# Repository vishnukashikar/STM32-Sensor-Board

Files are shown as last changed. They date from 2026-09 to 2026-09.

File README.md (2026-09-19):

# STM32 Sensor Board

A small custom board built around an **STM32C031C6** microcontroller and an **MPU-6050** 6-axis accelerometer/gyroscope (I2C), designed in KiCad.

**Status:** v1 (2026-09-17), design complete, not yet fabricated or tested.

This is a hardware design project: the repository contains the KiCad schematic and PCB layout only, with no firmware.

| Front | Back |
|---|---|
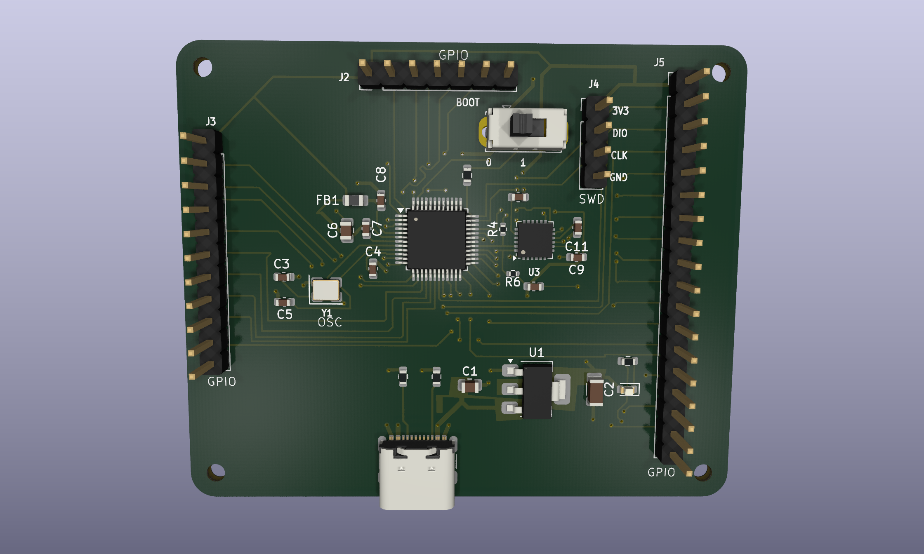
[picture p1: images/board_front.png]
Front
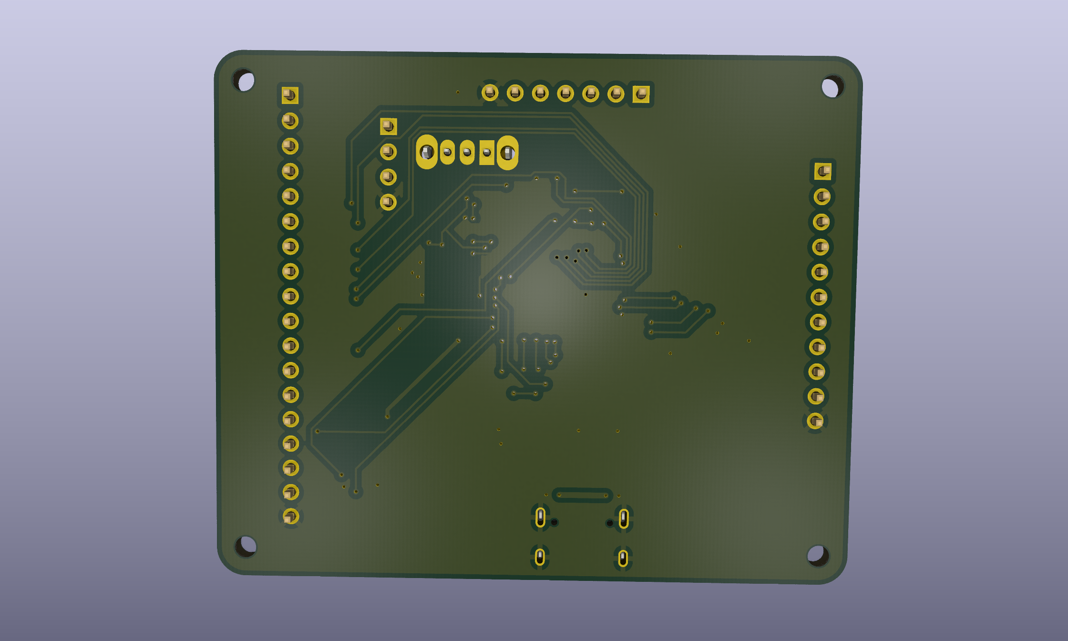
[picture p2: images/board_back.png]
Back
|  |  |

## Hardware overview

| Ref | Part | Role |
|---|---|---|
| U2 | STM32C031C6Tx (LQFP-48) | Main MCU |
| U3 | MPU-6050 (QFN-24, 4x4 mm) | Accelerometer + gyroscope |
| U1 | AMS1117-3.3 (SOT-223) | 5 V to 3.3 V regulator |
| J1 | USB-C receptacle | 5 V power input (VBUS) |
| Y1 | 16 MHz crystal (3225) with 16 pF load caps (C3, C5) | MCU clock |
| SW1 | SPDT slide switch | BOOT0 select (silkscreen: BOOT 0/1) |
| J4 | 1x4 header | SWD: 3V3, DIO, CLK, GND |
| J2, J3, J5 | 1x7, 1x11, 1x18 headers | GPIO breakout |
| D1 + R3 | LED + 300 ohm | Status LED |
| R4, R6 | 4.7 k | I2C pull-ups |
| FB1 + C6 | 120 ohm ferrite bead + 4.5 uF | Analog supply filtering (+3.3VA) |

Board: 2-layer, about 65.5 x 54 mm, four M2 mounting holes.

## Key connections

| Signal | U2 (MCU) pin | Goes to |
|---|---|---|
| I2C1_SCL | 29 | MPU-6050 SCL (U3 pin 23) |
| I2C1_SDA | 32 | MPU-6050 SDA (U3 pin 24) |
| MPU_INT | 33 | MPU-6050 INT (U3 pin 12) |
| SWCLK / SWDIO | 36 / 35 | J4 |
| NRST | 10 | Reset net |

The remaining MCU pins are broken out to J2, J3 and J5. See the schematic for the full pin mapping.

## Repository layout

```
hardware/   KiCad project (schematic, PCB, project file)
images/     3D renders of the board
```

## Programming and debug interface

The board exposes SWD on header J4 (3V3, DIO, CLK, GND). The USB-C port is used for power only; its data lines are not routed to the MCU.

## Opening the design

Open `hardware/stm32_sensor_board.kicad_pro` in KiCad.

## License

MIT, see [LICENSE](LICENSE).

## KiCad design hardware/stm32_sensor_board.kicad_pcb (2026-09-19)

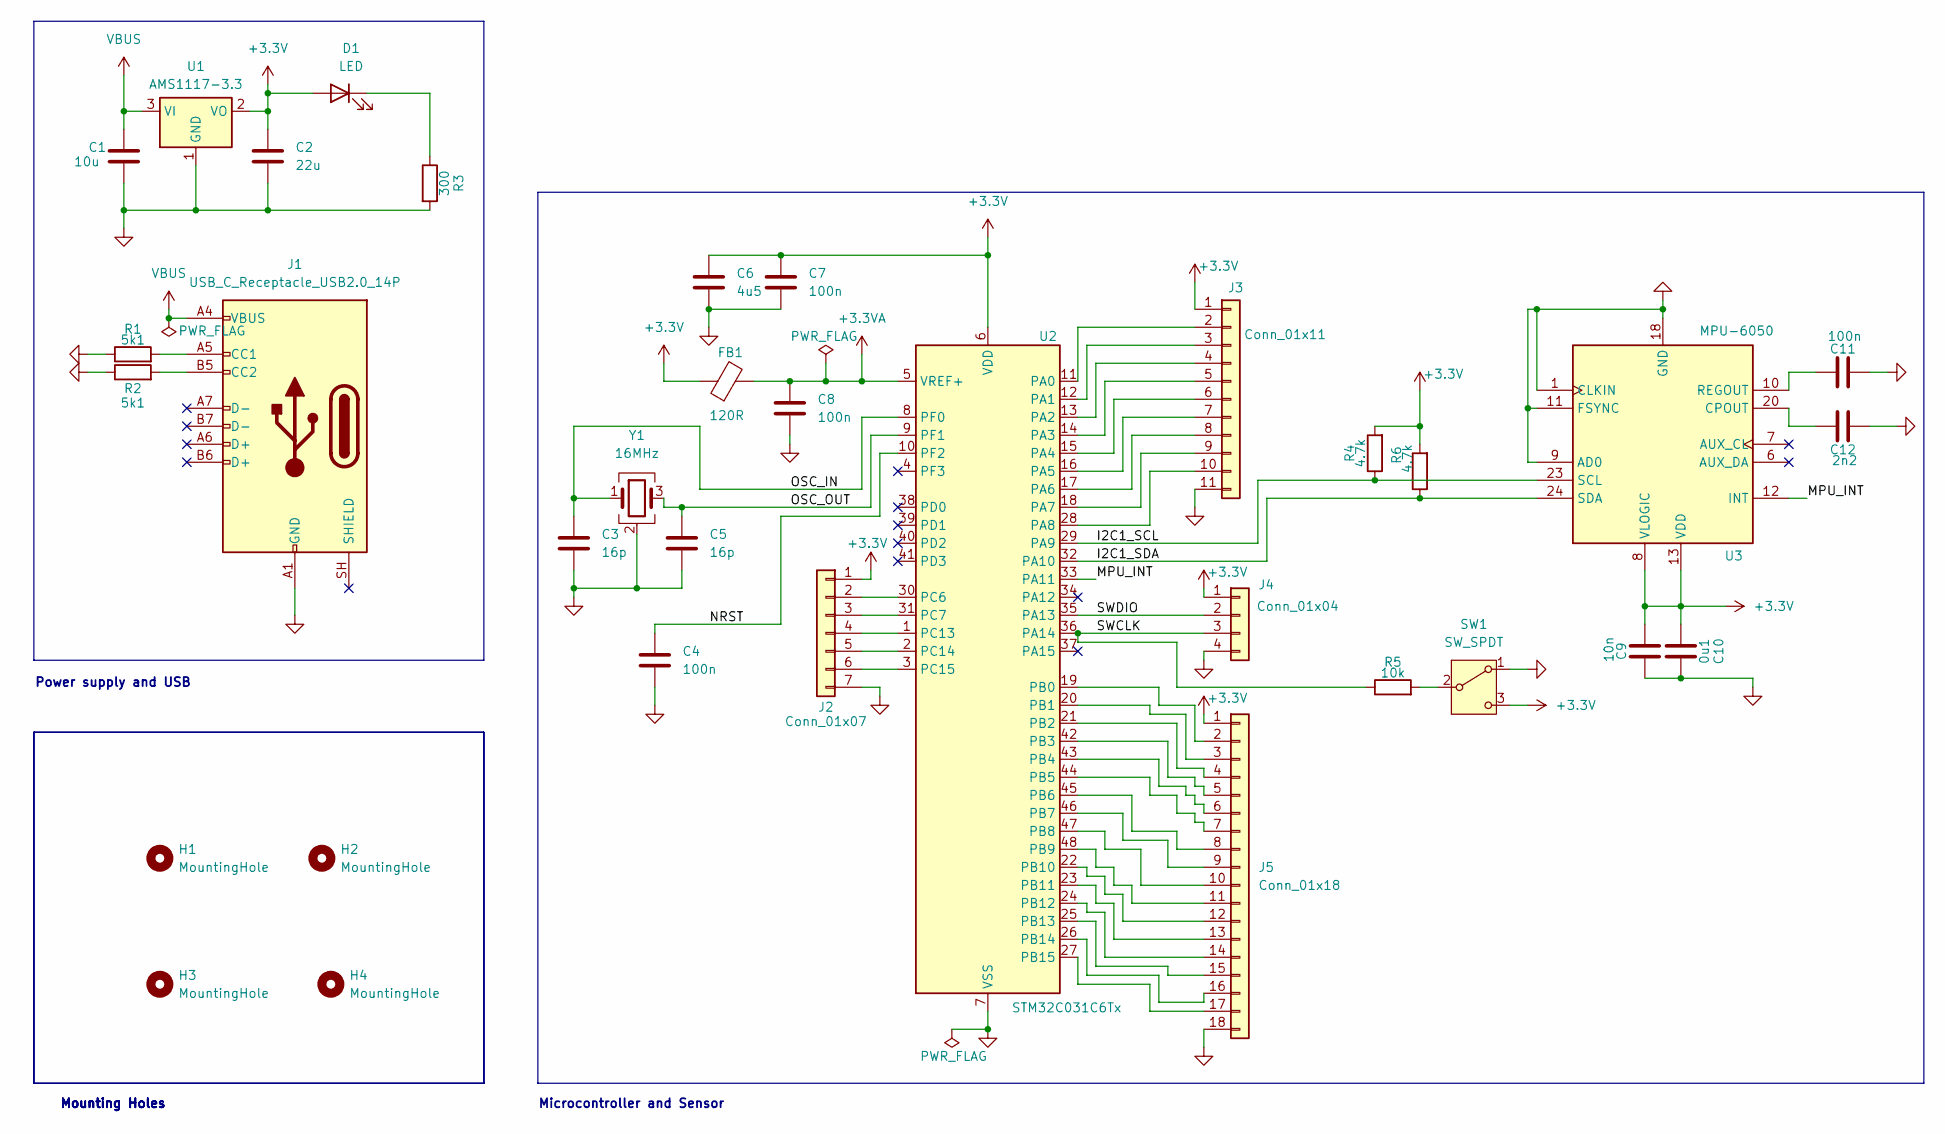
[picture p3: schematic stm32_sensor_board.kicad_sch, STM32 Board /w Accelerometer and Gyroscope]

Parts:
C1: 10u; C_0805_2012Metric
C2: 22u; C_1206_3216Metric
C3, C5: 16p; C_0603_1608Metric
C4, C7, C8, C11: 100n; C_0603_1608Metric
C6: 4u5; C_0805_2012Metric
C9: 10n; C_0603_1608Metric
C10: 0u1; C_0603_1608Metric
C12: 2n2; C_0603_1608Metric
D1: LED; LED_0603_1608Metric
FB1: 120R; L_0805_2012Metric
H1, H2, H3, H4: MountingHole; MountingHole_2.2mm_M2
J1: USB_C_Receptacle_USB2.0_14P; USB_C_Receptacle_GCT_USB4105-xx-A_16P_TopMnt_Horizontal
J2: Conn_01x07; PinHeader_1x07_P2.54mm_Vertical
J3: Conn_01x11; PinHeader_1x11_P2.54mm_Vertical
J4: Conn_01x04; PinHeader_1x04_P2.54mm_Vertical
J5: Conn_01x18; PinHeader_1x18_P2.54mm_Vertical
R1, R2: 5k1; R_0603_1608Metric
R3: 300; R_0603_1608Metric
R4, R6: 4.7k; R_0402_1005Metric
R5: 10k; R_0603_1608Metric
SW1: SW_SPDT; SW_Slide_SPDT_Straight_CK_OS102011MS2Q
U1: AMS1117-3.3; SOT-223-3_TabPin2
U2: STM32C031C6Tx; LQFP-48_7x7mm_P0.5mm
U3: MPU-6050; InvenSense_QFN-24_4x4mm_P0.5mm
Y1: 16MHz; Crystal_SMD_3225-4Pin_3.2x2.5mm

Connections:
+3.3V: C2.1, C6.1, C7.1, C9.2, C10.2, D1.2 (A), FB1.1, J2.1, J3.1, J4.1, J5.1, R4.2, R6.2, SW1.3 (C), U1.2 (VO), U2.6 (VDD), U3.8 (VLOGIC), U3.13 (VDD)
+3.3VA: C8.1, FB1.2, U2.5 (VREF+)
/I2C1_SCL: R4.1, U2.29 (PA9), U3.23 (SCL)
/I2C1_SDA: R6.1, U2.32 (PA10), U3.24 (SDA)
/MPU_INT: U2.33 (PA11), U3.12 (INT)
/NRST: C4.1, U2.10 (PF2)
/OSC_IN: C3.1, U2.8 (PF0), Y1.1
/OSC_OUT: C5.1, U2.9 (PF1), Y1.3
/SWCLK: J4.3, R5.1, U2.36 (PA14)
/SWDIO: J4.2, U2.35 (PA13)
GND: C1.2, C2.2, C3.2, C4.2, C5.2, C6.2, C7.2, C8.2, C9.1, C10.1, C11.2, C12.2, J1.A1 (GND), J1.A12 (GND), J1.B1 (GND), J1.B12 (GND), J1.SH (SHIELD), J2.7, J3.11, J4.4, J5.18, R1.1, R2.1, R3.2, SW1.1 (A), U1.1 (GND), U2.7 (VSS), U3.1 (CLKIN), U3.9 (AD0), U3.11 (FSYNC), U3.18 (GND), Y1.2 (G), Y1.4 (G)
unnamed: D1.1 (K), R3.1
unnamed: J1.A5 (CC1), R1.2
unnamed: J1.B5 (CC2), R2.2
unnamed: J2.2, U2.30 (PC6)
unnamed: J2.3, U2.31 (PC7)
unnamed: J2.4, U2.1 (PC13)
unnamed: J2.5, U2.2 (PC14)
unnamed: J2.6, U2.3 (PC15)
unnamed: J3.2, U2.11 (PA0)
unnamed: J3.3, U2.12 (PA1)
unnamed: J3.4, U2.13 (PA2)
unnamed: J3.5, U2.14 (PA3)
unnamed: J3.6, U2.15 (PA4)
unnamed: J3.7, U2.16 (PA5)
unnamed: J3.8, U2.17 (PA6)
unnamed: J3.9, U2.18 (PA7)
unnamed: J3.10, U2.28 (PA8)
unnamed: J5.2, U2.19 (PB0)
unnamed: J5.3, U2.20 (PB1)
unnamed: J5.4, U2.21 (PB2)
unnamed: J5.5, U2.42 (PB3)
unnamed: J5.6, U2.43 (PB4)
unnamed: J5.7, U2.44 (PB5)
unnamed: J5.8, U2.45 (PB6)
unnamed: J5.9, U2.46 (PB7)
unnamed: J5.10, U2.47 (PB8)
unnamed: J5.11, U2.48 (PB9)
unnamed: J5.12, U2.22 (PB10)
unnamed: J5.13, U2.23 (PB11)
unnamed: J5.14, U2.24 (PB12)
unnamed: J5.15, U2.25 (PB13)
unnamed: J5.16, U2.26 (PB14)
unnamed: J5.17, U2.27 (PB15)
unnamed: R5.2, SW1.2 (B)
unnamed: C12.1, U3.20 (CPOUT)
unnamed: C11.1, U3.10 (REGOUT)
VBUS: C1.1, J1.A4 (VBUS), J1.A9 (VBUS), J1.B4 (VBUS), J1.B9 (VBUS), U1.3 (VI)

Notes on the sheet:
Mounting Holes
Power supply and USB
Microcontroller and Sensor

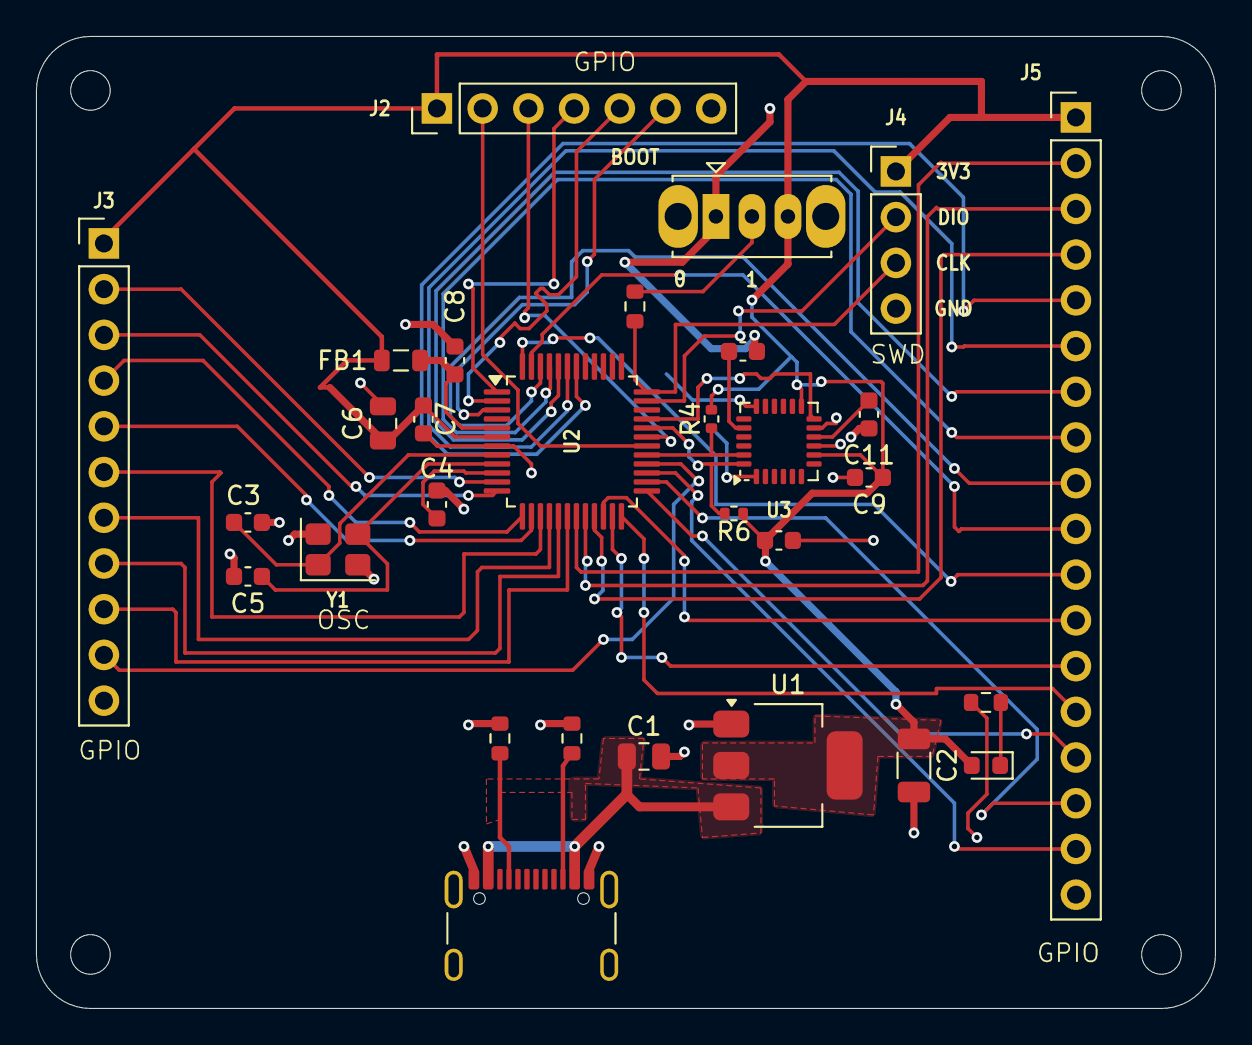
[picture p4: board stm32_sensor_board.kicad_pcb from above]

Board: 2 copper layers, 65.5 x 54.0 mm, 34 parts (0 on the bottom side), 48 nets.
